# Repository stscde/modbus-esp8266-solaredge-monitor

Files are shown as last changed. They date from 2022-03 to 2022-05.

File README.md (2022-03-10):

# SolarEdge Modbus Monitor for ESP8266

This project builds a hardware monitor to show values from a SolarEdge inverter on an OLED 0.96" display.

Here is a picture of the assembled monitor showing solar data.

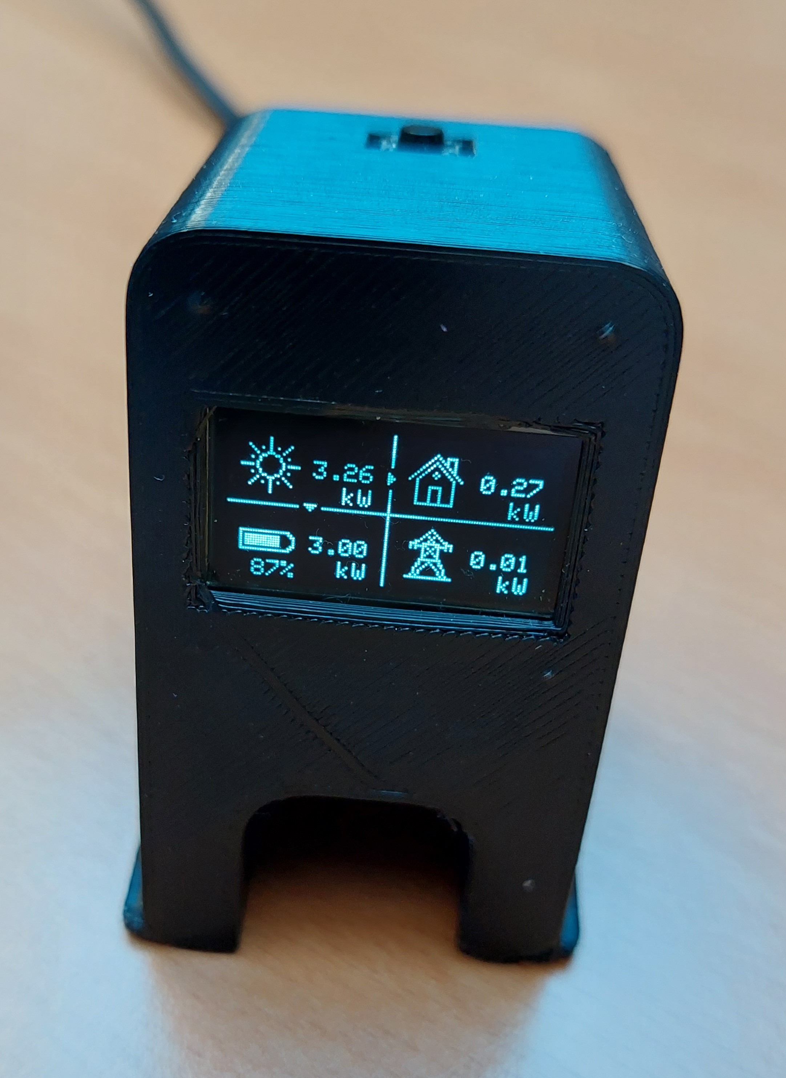
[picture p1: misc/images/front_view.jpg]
Front view


This is how the back looks like. There is a hole for connecting the monitor with USB to power or programm it.

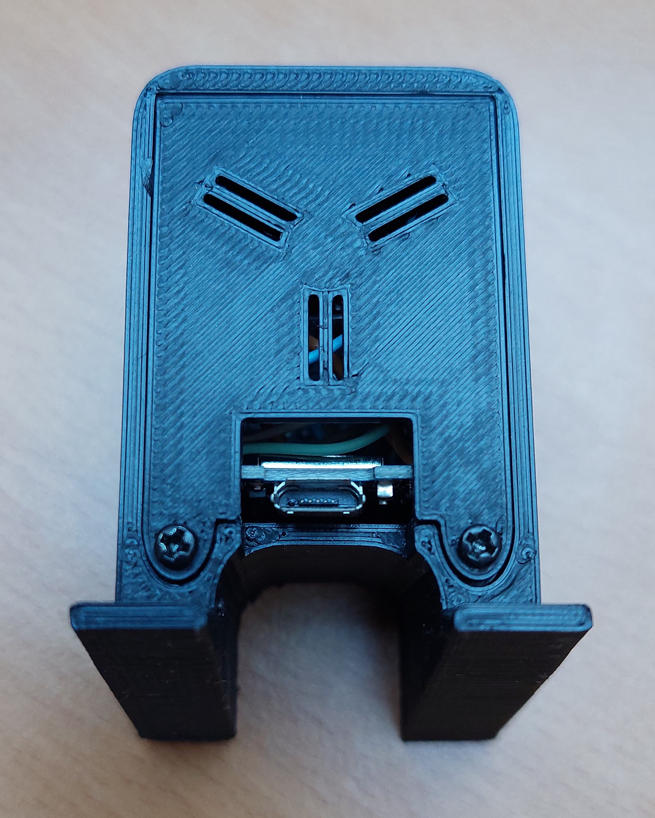
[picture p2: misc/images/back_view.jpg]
Back view


## Features

* Displays solar energy intensity
* Displays battery charge/discharge and loading state
* Displays power usage
* Displays power transfer from/to grid
* Web config interface for WIFI and Modbus connection data
* Switch button for multiple screens

## Environment

* Tested with ESP8266 on Wemos D1 mini
* Tested with SolarEdge SE7K inverter with BYD battery box
* Tested with Modbus over TCP

## Housing

I used a housing called [3D Printer Monitor for OctoPrint Wemos D1 ESP8266](https://www.thingiverse.com/thing:2884823) from [Thingiverse](https://www.thingiverse.com) build by [Qrome](https://www.thingiverse.com/qrome/designs). Many thanks for this design.

## Parts and wiring

Required parts

* Wemos D1 mini (1x)
* 0.96 incl OLED display with I2C bus (1x)
* 10k resistor (1x)
* push button (1x)

The following image shows the components and their wiring.

Electric components and wiring

## Configuration

When you start the monitor for the first time it will display "Init WiFi connection - Access Point Mode" or "Init WiFi connection - Not configured".
In both states the monitor opens an WiFi access point with SSID "SolarEdgeMonitor". Connect to this access point using your mobile or tablet. 

After the connection has been established the following config screen is shown. Fill in the values according to your environment.

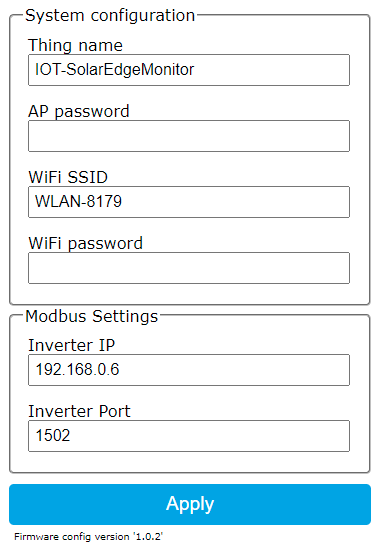
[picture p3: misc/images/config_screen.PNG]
Config screen


* Thing name: Name of the monitor in the network
* AP password: Password of the monitor´s access point. Will be required when you reconnect to the monitor after completing the configuration.
* WiFi SSID: SSID of the WiFi you want the monitor to connect to. The SolarEdge inverter has to be reachable from that WiFi.
* WiFi password: Password of the WiFi.

* Inverter IP: IP address of the SolarEdge inverter
* Inverter port: Modbus port of the SolarEge inverter

### Modbus Proxy

As my SolarEdge inverter accepts only one Modbus client I use [modbus-proxy](https://pypi.org/project/modbus-proxy/) on a Raspberry Pi. 
The proxy makes it possible for multiple clients to query data from the inverter. If you have only one client like this SolarEdge monitor connecting to the inverter you can live without a proxy of course.

### Configuration reset
You can reset the configuration by pressing the button for about 5 seconds. The display will show "Configuration reset - press again to reset". 
Press again to reset the configuration or remove power to prevent a config reset.

## Screens

There are two screens available at the moment which can be toggled by double clicking the button.

### Screen 1

Screen 1 is made up of four quadrants.

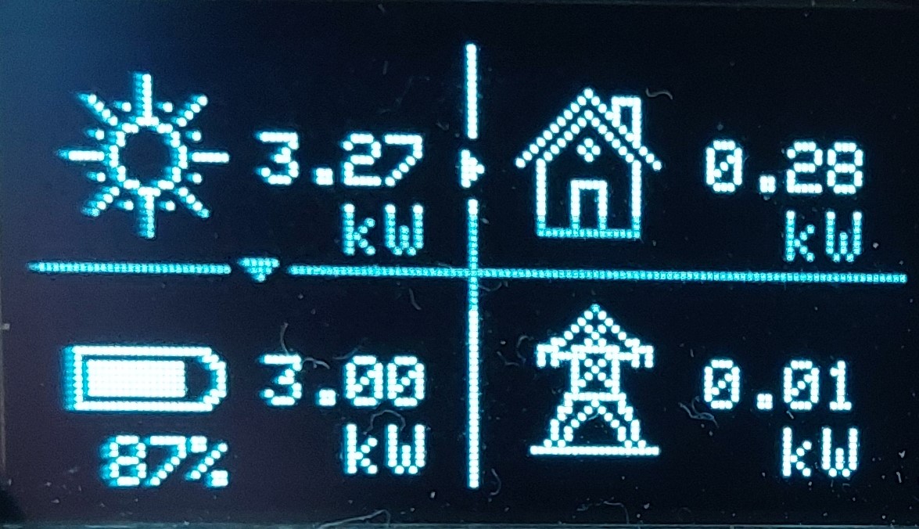
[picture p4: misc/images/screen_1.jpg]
Screen 1


* Top left - sun: shows the current power the inverter produces from the solar panels
* Bottom left - battery: shows the power transfered to (loading) and from the battery (discharging) and the fill grade of the battery.
* Top right: house: shows the power used by the house.
* Bottom right - grid: shows the power received from or sent to the power grid.

The little triangled arrows between the quadrants indicate the direction of the power flow. Example: In case the top of the triangle is pointing towards the battery then the battery is loading.

### Screen 2

Non graphical representation of the data from screen 1. Primarly used for testing screen toggling and reserved for further extensions.

## Libraries

This project uses the following libraries. Thanks to all creators and contributors.

* [emelianov/modbus-esp8266](https://github.com/emelianov/modbus-esp8266)
* [stscde/modbus-esp8266-solaredge](https://github.com/stscde/modbus-esp8266-solaredge)
* OneButton
* IotWebConf
* several Adafruit libraries

## Building

This library was created using [PlatformIO](https://platformio.org/) for [Visual Studio Code](https://code.visualstudio.com/).

To build the project with PlatformIO use the following steps:

* clone the repository from GitHub to your workspace
* compile and upload

## Last Changes

* first release no changes yet

## License

The code in this repo is licensed under the BSD New License. See LICENSE.txt for more info.

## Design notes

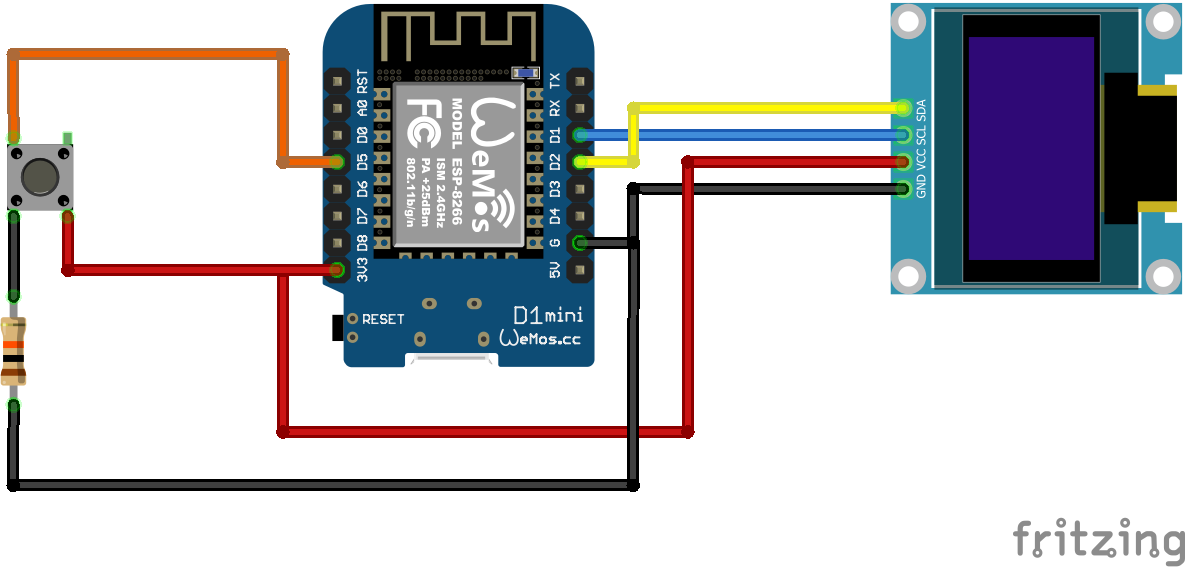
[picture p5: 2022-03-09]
misc/fritzing/solaredge_monitor.png

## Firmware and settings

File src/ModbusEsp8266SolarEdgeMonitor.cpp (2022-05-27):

#include <Adafruit_GFX.h>
#include <Adafruit_I2CDevice.h>
#include <Adafruit_SSD1306.h>
#include <Arduino.h>
#include <Fonts/FreeMono9pt7b.h>

#define IOTWEBCONF_PASSWORD_LEN 65
#include <IotWebConf.h>
#include <IotWebConfUsing.h>  // This loads aliases for easier class names.
#include <ModbusSolarEdge.h>
#include <OneButton.h>
#include <SPI.h>
#include <Wire.h>



// ### Network and modbus #####################################################
// ############################################################################


// Name server
DNSServer dnsServer;

// Web server
WebServer server(80);

// IP of the SolarEdge inverter
IPAddress remote;

// Modbus port of the SolarEdge inverter
int port = -1;

// ModbusIP object
ModbusIP mb;

// Modbus SolarEdge helper
ModbusSolarEdge mbse;


// ### IotWebConf #############################################################
// ############################################################################

// Is a reset required?
boolean needReset = false;

// Is wifi connected?
boolean connected = false;

// IotWebConf: Modifying the config version will probably cause a loss of the existig configuration. Be careful!
const char *CONFIG_VERSION = "1.0.2";

// IotWebConf: Access point SSID
const char *WIFI_AP_SSID = "SolarEdgeMonitor";

// IotWebConf: Default access point password
const char *WIFI_AP_DEFAULT_PASSWORD = "";

// IotWebConf: Method for handling access to / on web config
void handleRoot();

// IotWebConf: Called when connection to wifi was established
void wifiConnected();

// IotWebConf: Called when configuration saved
void configSaved();

// last known WiFi network state
iotwebconf::NetworkState lastNetWorkState = iotwebconf::NetworkState::OffLine;

IotWebConf iotWebConf(WIFI_AP_SSID, &dnsServer, &server, WIFI_AP_DEFAULT_PASSWORD, CONFIG_VERSION);

// Parameter group for inverter parameter
IotWebConfParameterGroup groupModbus = IotWebConfParameterGroup("groupModbus", "Modbus Settings");

// Parameter for inverter IP address
char inverterIpAddressParamValue[15] = {""};
IotWebConfTextParameter inverterIpAddressParam = IotWebConfTextParameter("Inverter IP", "inverterIpParam", inverterIpAddressParamValue, 15, "192.168.0.1");

// Parameter for Modbus TCP port
char inverterPortParamValue[32];
IotWebConfNumberParameter inverterPortParam = IotWebConfNumberParameter("Inverter Port", "inverterPort", inverterPortParamValue, 32, "1502", "1..65535", "min='1' max='65535' step='1'");


// ### Screens ################################################################
// ############################################################################

#define SCREEN_WIDTH 128  // OLED display width, in pixels
#define SCREEN_HEIGHT 64  // OLED display height, in pixels

// Declaration for an SSD1306 display connected to I2C (SDA, SCL pins)
#define OLED_RESET 0         // Reset pin # (or -1 if sharing Arduino reset pin)
#define SCREEN_ADDRESS 0x3C  ///< See datasheet for Address; 0x3D for 128x64, 0x3C for 128x32
Adafruit_SSD1306 display(SCREEN_WIDTH, SCREEN_HEIGHT, &Wire, OLED_RESET);

// which screen is currently shown
enum CurrentScreen {
    None,
    WifiState,
    Solar1,
    Solar2
};

// At boot time no screen is shown
CurrentScreen lastScreen = None;

// Time since display is on
long displayOnSince;

// Turn display off after this time in minutes to reduce OLED wearing, 0 = always on
const int DISPLAY_OFF_AFTER_MINS = 15;

// Time since last display update
long lastDisplayUpdateTime = 0;

// Update interval for display
const int DISPLAY_UPDATE_INTERVAL_SECS = 5;

// Is the display on?
boolean displayOn = true;

// Print graphical screen with solar power, battery power, house usage and grid consumption
void printStateScreen1(char *sunPowerStr, char *houseUsagePower, char *meterPower = nullptr, char *batteryPower = nullptr, char *batteryLevelOfEnergy = nullptr, float batteryLevelOfEnergyPct = 0.0f, float sunPowerPowerKw = 0.0f, float meterPowerKw = 0.0f, float houseUsagePowerKw = 0.0f, float batteryPowerKw = 0.0f, float i_ac_power_norm = 0.0f);

// Prints a simple 4 lined screen used for multiple purposes
void printStateScreen2(char *line1, char *line2, char *line3 = nullptr, char *line4 = nullptr);

// Print wifi state screen
void printWifiState();

// Main method for printing solar system usage values
void printUsage();


// ### OneButton ##############################################################
// ############################################################################

// OneButton: Handle single click
void handleClick();

// OneButton: Handle double click
void handleDoubleClick();

// OneButton: Handle long press stop
void handleLongPressStop();

OneButton btn = OneButton(
    D5,     // Input pin for the button
    false,  // Button is active LOW
    false   // Enable internal pull-up resistor
);

// Count how many times the button was pressed for a long time
int longPressCount = 0;

// ### Other method declarations ##############################################
// ############################################################################

// Helper method for rounding
float hlpRound(float f);


// ### Images #################################################################
// ############################################################################

// '211105_solaredige_mon_screen', 128x64px
const unsigned char img_background[] PROGMEM = {
    0x00, 0x00, 0x00, 0x00, 0x00, 0x00, 0x00, 0x01, 0x00, 0x00, 0x00, 0x00, 0x00, 0x00, 0x00, 0x00,
    0x00, 0x00, 0x00, 0x00, 0x00, 0x00, 0x00, 0x01, 0x00, 0x00, 0x00, 0x00, 0x00, 0x00, 0x00, 0x00,
    0x00, 0x00, 0x00, 0x00, 0x00, 0x00, 0x00, 0x01, 0x00, 0x00, 0x00, 0x00, 0x00, 0x00, 0x00, 0x00,
    0x00, 0x00, 0x00, 0x00, 0x00, 0x00, 0x00, 0x01, 0x00, 0x00, 0x00, 0x00, 0x00, 0x00, 0x00, 0x00,
    0x00, 0x00, 0x00, 0x00, 0x00, 0x00, 0x00, 0x01, 0x00, 0x00, 0x00, 0x00, 0x00, 0x00, 0x00, 0x00,
    0x00, 0x00, 0x80, 0x00, 0x00, 0x00, 0x00, 0x01, 0x00, 0x00, 0x00, 0x00, 0x00, 0x00, 0x00, 0x00,
    0x00, 0x00, 0x80, 0x00, 0x00, 0x00, 0x00, 0x01, 0x00, 0x00, 0x80, 0x00, 0x00, 0x00, 0x00, 0x00,
    0x00, 0x00, 0x80, 0x00, 0x00, 0x00, 0x00, 0x01, 0x00, 0x01, 0x4f, 0x00, 0x00, 0x00, 0x00, 0x00,
    0x00, 0x80, 0x80, 0x80, 0x00, 0x00, 0x00, 0x01, 0x00, 0x02, 0x29, 0x00, 0x00, 0x00, 0x00, 0x00,
    0x00, 0x44, 0x91, 0x00, 0x00, 0x00, 0x00, 0x01, 0x00, 0x04, 0x99, 0x00, 0x00, 0x00, 0x00, 0x00,
    0x00, 0x20, 0x82, 0x00, 0x00, 0x00, 0x00, 0x01, 0x00, 0x09, 0x49, 0x00, 0x00, 0x00, 0x00, 0x00,
    0x00, 0x11, 0xc4, 0x00, 0x00, 0x00, 0x00, 0x01, 0x00, 0x12, 0x25, 0x00, 0x00, 0x00, 0x00, 0x00,
    0x00, 0x06, 0x30, 0x00, 0x00, 0x00, 0x00, 0x01, 0x00, 0x24, 0x13, 0x00, 0x00, 0x00, 0x00, 0x00,
    0x00, 0x48, 0x09, 0x00, 0x00, 0x00, 0x00, 0x01, 0x00, 0x48, 0x89, 0x00, 0x00, 0x00, 0x00, 0x00,
    0x00, 0x08, 0x08, 0x00, 0x00, 0x00, 0x00, 0x01, 0x00, 0x91, 0x44, 0x80, 0x00, 0x00, 0x00, 0x00,
    0x00, 0x10, 0x04, 0x00, 0x00, 0x00, 0x00, 0x01, 0x01, 0x20, 0x82, 0x40, 0x00, 0x00, 0x00, 0x00,
    0x07, 0xd0, 0x05, 0xf0, 0x00, 0x00, 0x00, 0x01, 0x02, 0x40, 0x01, 0x20, 0x00, 0x00, 0x00, 0x00,
    0x00, 0x10, 0x04, 0x00, 0x00, 0x00, 0x00, 0x01, 0x00, 0x40, 0x01, 0x00, 0x00, 0x00, 0x00, 0x00,
    0x00, 0x08, 0x08, 0x00, 0x00, 0x00, 0x00, 0x01, 0x00, 0x40, 0x01, 0x00, 0x00, 0x00, 0x00, 0x00,
    0x00, 0x48, 0x09, 0x00, 0x00, 0x00, 0x00, 0x01, 0x00, 0x43, 0xe1, 0x00, 0x00, 0x00, 0x00, 0x00,
    0x00, 0x06, 0x30, 0x00, 0x00, 0x00, 0x00, 0x01, 0x00, 0x42, 0x21, 0x00, 0x00, 0x00, 0x00, 0x00,
    0x00, 0x11, 0xc4, 0x00, 0x00, 0x00, 0x00, 0x01, 0x00, 0x42, 0x21, 0x00, 0x00, 0x00, 0x00, 0x00,
    0x00, 0x20, 0x82, 0x00, 0x00, 0x00, 0x00, 0x01, 0x00, 0x42, 0x21, 0x00, 0x00, 0x00, 0x00, 0x00,
    0x00, 0x44, 0x91, 0x00, 0x00, 0x00, 0x00, 0x01, 0x00, 0x42, 0x21, 0x00, 0x00, 0x00, 0x00, 0x00,
    0x00, 0x80, 0x80, 0x80, 0x00, 0x00, 0x00, 0x01, 0x00, 0x42, 0x21, 0x00, 0x00, 0x00, 0x00, 0x00,
    0x00, 0x00, 0x80, 0x00, 0x00, 0x00, 0x00, 0x01, 0x00, 0x42, 0x21, 0x00, 0x00, 0x00, 0x00, 0x00,
    0x00, 0x00, 0x80, 0x00, 0x00, 0x00, 0x00, 0x01, 0x00, 0x7f, 0xff, 0x00, 0x00, 0x00, 0x00, 0x00,
    0x00, 0x00, 0x80, 0x00, 0x00, 0x00, 0x00, 0x01, 0x00, 0x00, 0x00, 0x00, 0x00, 0x00, 0x00, 0x00,
    0x00, 0x00, 0x00, 0x00, 0x00, 0x00, 0x00, 0x01, 0x00, 0x00, 0x00, 0x00, 0x00, 0x00, 0x00, 0x00,
    0x00, 0x00, 0x00, 0x00, 0x00, 0x00, 0x00, 0x01, 0x00, 0x00, 0x00, 0x00, 0x00, 0x00, 0x00, 0x00,
    0x00, 0x00, 0x00, 0x00, 0x00, 0x00, 0x00, 0x01, 0x00, 0x00, 0x00, 0x00, 0x00, 0x00, 0x00, 0x00,
    0x00, 0x00, 0x00, 0x00, 0x00, 0x00, 0x00, 0x01, 0x00, 0x00, 0x00, 0x00, 0x00, 0x00, 0x00, 0x00,
    0xff, 0xff, 0xff, 0xff, 0xff, 0xff, 0xff, 0xff, 0xff, 0xff, 0xff, 0xff, 0xff, 0xff, 0xff, 0xff,
    0x00, 0x00, 0x00, 0x00, 0x00, 0x00, 0x00, 0x01, 0x00, 0x00, 0x00, 0x00, 0x00, 0x00, 0x00, 0x00,
    0x00, 0x00, 0x00, 0x00, 0x00, 0x00, 0x00, 0x01, 0x00, 0x00, 0x00, 0x00, 0x00, 0x00, 0x00, 0x00,
    0x00, 0x00, 0x00, 0x00, 0x00, 0x00, 0x00, 0x01, 0x00, 0x00, 0x00, 0x00, 0x00, 0x00, 0x00, 0x00,
    0x00, 0x00, 0x00, 0x00, 0x00, 0x00, 0x00, 0x01, 0x00, 0x00, 0x00, 0x00, 0x00, 0x00, 0x00, 0x00,
    0x00, 0x00, 0x00, 0x00, 0x00, 0x00, 0x00, 0x01, 0x00, 0x00, 0x40, 0x00, 0x00, 0x00, 0x00, 0x00,
    0x00, 0x00, 0x00, 0x00, 0x00, 0x00, 0x00, 0x01, 0x00, 0x00, 0xa0, 0x00, 0x00, 0x00, 0x00, 0x00,
    0x00, 0x00, 0x00, 0x00, 0x00, 0x00, 0x00, 0x01, 0x00, 0x01, 0x10, 0x00, 0x00, 0x00, 0x00, 0x00,
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

const unsigned char img_arr_right_3x7[] PROGMEM = {
    0x00, 0x80, 0xc0, 0xe0, 0xc0, 0x80, 0x00};

// '210511_pfeil_3x7_hoch', 7x3px
const unsigned char img_arr_up_7x3[] PROGMEM = {
    0x10, 0x38, 0x7c};

// '210511_pfeil_3x7_runter', 7x3px
const unsigned char img_arr_down_7x3[] PROGMEM = {
    0x7c, 0x38, 0x10};


// ### Setup ##################################################################
// ############################################################################

void setup() {
    Serial.begin(115200);  // Start the Serial communication to send messages to the computer
    delay(10);
    Serial.println("Starting up...");

    // SSD1306_SWITCHCAPVCC = generate display voltage from 3.3V internally
    if (!display.begin(SSD1306_SWITCHCAPVCC, 0x3C)) {  // Address 0x3C for 128x64
        Serial.println(F("SSD1306 allocation failed"));
        for (;;)
            ;  // Don't proceed, loop forever
    }
    // display is built in upside down
    display.setRotation(2);
    display.clearDisplay();

    displayOnSince = millis();

    // -- Initializing the configuration.
    groupModbus.addItem(&inverterIpAddressParam);
    groupModbus.addItem(&inverterPortParam);
    iotWebConf.addParameterGroup(&groupModbus);

    iotWebConf.setWifiConnectionCallback(&wifiConnected);
    iotWebConf.setConfigSavedCallback(&configSaved);
    iotWebConf.setStatusPin(LED_BUILTIN);
    //iotWebConf.setConfigPin(D5);
    iotWebConf.init();

    // -- Set up required URL handlers on the web server.
    server.on("/", [] { iotWebConf.handleConfig(); });
    server.onNotFound([]() { iotWebConf.handleNotFound(); });

    mb.client();

    btn.attachClick(handleClick);
    btn.attachDoubleClick(handleDoubleClick);
    btn.attachLongPressStop(handleLongPressStop);

    Serial.println("setup done");
}


// ### Main ###################################################################
// ############################################################################

void loop() {
    if (needReset) {
        // config changes require reset
        Serial.println("restart in 1 sec");
        delay(1000);
        ESP.restart();
    }

    if (!connected) {
        printWifiState();
    }

    if (connected) {
        if (!mb.isConnected(remote)) {
            Serial.print("Inverter IP address: ");
            Serial.println(inverterIpAddressParamValue);
            Serial.print("Inverter TCP port: ");
            Serial.println(inverterPortParamValue);

            String line1 = "Init Modbus client";
            String ipStr(inverterIpAddressParamValue);
            String line2 = "IP: " + ipStr;
            String portStr(inverterPortParamValue);
            String line3 = "Port: " + portStr;
            String line4 = "";

            port = atoi(inverterPortParamValue);

            boolean valid = remote.fromString(inverterIpAddressParamValue);
            if (!valid) {
                line4 = "> IP is invalid";
            }
            printStateScreen2(&line1[0], &line2[0], &line3[0], &line4[0]);
            delay(2000);

            if (valid) {
                boolean connected = mb.connect(remote, port);
                line4 = connected ? "> Modbus connected" : "> Modbus conn. failed";
                printStateScreen2(&line1[0], &line2[0], &line3[0], &line4[0]);
                delay(2000);
            }
        } else {
            if ((int)millis() > lastDisplayUpdateTime + DISPLAY_UPDATE_INTERVAL_SECS * 1000 && displayOn) {
                // init to Solar1
                lastScreen = lastScreen == None || lastScreen == WifiState ? Solar1 : lastScreen;

                printUsage();

                lastDisplayUpdateTime = millis();
            }

            if (DISPLAY_OFF_AFTER_MINS != 0 && (int)millis() > displayOnSince + DISPLAY_OFF_AFTER_MINS * 60 * 1000) {
                display.ssd1306_command(SSD1306_DISPLAYOFF);
                displayOn = false;
            } else if (!displayOn) {
                display.ssd1306_command(SSD1306_DISPLAYON);
                displayOn = true;
            }
        }
    }

    iotWebConf.doLoop();
    btn.tick();
}

void handleClick() {
    Serial.println("Clicked!");
    displayOnSince = millis();  // activate Display if off
}

void handleDoubleClick() {
    Serial.println("Double Clicked!");
    displayOnSince = millis();  // activate Display if off

    if (lastScreen == Solar1) {
        lastScreen = Solar2;
    } else if (lastScreen == Solar2) {
        lastScreen = Solar1;
    }

    lastDisplayUpdateTime = 0;
}


void handleLongPressStop() {
    longPressCount++;

    String line1 = "Reset configuration";
    String line2 = "";
    String line3 = "";

    if (longPressCount == 1) {
        line2 = "Press again to reset";
        printStateScreen2(&line1[0], &line2[0], &line3[0]);
        delay(5000);
    }
    else {
        line2 = "Reset started";
        printStateScreen2(&line1[0], &line2[0], &line3[0]);
        iotWebConf.getSystemParameterGroup()->applyDefaultValue();
        iotWebConf.saveConfig();
        needReset = true;
        delay(2000);

        line2 = "Config erased";
        line3 = "Rebooting";
        printStateScreen2(&line1[0], &line2[0], &line3[0]);
        delay(5000);
    }

}

void configSaved() {
    Serial.println("config saved");
    needReset = true;
}

void wifiConnected() {
    connected = true;
    Serial.println("wifi connected");

    // hack for getting hostname set correctly
    WiFi.hostname(iotWebConf.getThingName());
    WiFi.begin();
}

void printWifiState() {
    if (iotWebConf.getState() != lastNetWorkState || lastScreen != WifiState) {
        String state = "";
        switch (iotWebConf.getState()) {
            case iotwebconf::NetworkState::ApMode:
                state = "Access Point Mode";
                break;
            case iotwebconf::NetworkState::Boot:
                state = "Booting";
                break;
            case iotwebconf::NetworkState::Connecting:
                state = "Connecting to WiFi";
                break;
            case iotwebconf::NetworkState::NotConfigured:
                state = "Not configured";
                break;
            case iotwebconf::NetworkState::OffLine:
                state = "Offline";
                break;
            case iotwebconf::NetworkState::OnLine:
                state = "Online";
                break;
        }

        String initString = "Init WiFi connection";
        printStateScreen2(&initString[0], &state[0]);

        lastNetWorkState = iotWebConf.getState();
        lastScreen = WifiState;
    }
}

void printStateScreen2(char *line1, char *line2, char *line3, char *line4) {
    display.clearDisplay();

    display.setTextSize(1);
    display.setTextColor(SSD1306_WHITE);
    display.setCursor(2, 2);
    display.println(line1);

    display.setCursor(2, 12);
    display.println(line2);

    if (line3 != nullptr) {
        display.setCursor(2, 22);
        display.println(line3);
    }

    if (line4 != nullptr) {
        display.setCursor(2, 32);
        display.println(line4);
    }

    display.display();
    delay(500);
}

void printStateScreen1(char *sunPowerStr, char *houseUsagePower, char *meterPower, char *batteryPower, char *batteryLevelOfEnergy, float batteryLevelOfEnergyPct, float sunPowerPowerKw, float meterPowerKw, float houseUsagePowerKw, float batteryPowerKw, float i_ac_power_norm) {
    display.clearDisplay();

    display.drawBitmap(0, 0, img_background, 128, 64, 1);

    display.setTextSize(1);
    display.setTextColor(SSD1306_WHITE);

    // #######
    // # Sun #
    // #######
    display.setCursor(33, 13);
    display.println(sunPowerStr);
    display.setCursor(33, 23);
    display.println("  kW");

    // #########
    // # House #
    // #########
    display.setCursor(98, 13);
    display.println(houseUsagePower);
    display.setCursor(98, 23);
    display.println("  kW");

    // print pv system to house power flow arrow
    if (i_ac_power_norm > 0) {
        display.fillRect(63, 13, 6, 9, SSD1306_BLACK);
        display.drawBitmap(62, 14, img_arr_right_3x7, 3, 7, 1);
    }

    // ###########
    // # Battery #
    // ###########

    float batteryPowerKwAbs = batteryPowerKw < 0 ? batteryPowerKw * -1 : batteryPowerKw;
    char batteryPowerFmt[4];
    dtostrf(batteryPowerKwAbs, 4, 2, batteryPowerFmt);
    String batteryPowerAbsStr(batteryPowerFmt);

    display.setCursor(33, 45);
    display.println(batteryPowerAbsStr);
    display.setCursor(33, 55);
    display.println("  kW");

    String batteryLevelOfEnergyFmt(batteryLevelOfEnergy);
    batteryLevelOfEnergyFmt += "%";

    display.setCursor(4, 57);
    display.println(batteryLevelOfEnergyFmt);

    // draw battery charge level
    const int BATT_X = 7;
    const int BATT_Y = 46;
    const int BATT_WIDTH = 17;
    const int BATT_HEIGHT = 5;

    float width = batteryLevelOfEnergyPct * BATT_WIDTH / 100.0f;
    display.fillRect(BATT_X, BATT_Y, (int)width, BATT_HEIGHT, SSD1306_WHITE);

    // print battery power flow arrow
    long batteryPowerWAbs = batteryPowerKw > 0 ? batteryPowerKw * 1000 : batteryPowerKw * -1000;
    // Serial.print("battery power w: ");
    // Serial.println(batteryPowerWAbs);
    if (batteryPowerWAbs > 9) {
        display.fillRect(28, 29, 9, 6, SSD1306_BLACK);
        if (batteryPowerKw < 0) {
            display.drawBitmap(29, 31, img_arr_up_7x3, 7, 3, 1);
        } else {
            display.drawBitmap(29, 31, img_arr_down_7x3, 7, 3, 1);
        }
    }

    // #########
    // # Meter #
    // #########

    float meterPowerKwAbs = meterPowerKw < 0 ? meterPowerKw * -1 : meterPowerKw;
    char meterPowerFmt[4];
    dtostrf(meterPowerKwAbs, 4, 2, meterPowerFmt);
    String meterPowerAbsStr(meterPowerFmt);

    display.setCursor(98, 45);
    display.println(meterPowerAbsStr);
    display.setCursor(98, 55);
    display.println("  kW");

    long meterPowerWAbs = meterPowerKwAbs * 1000;
    // print meter power flow arrow
    if (meterPowerWAbs > 9) {
        // Serial.print("meter active w: ");
        // Serial.println(meterPowerWAbs);
        display.fillRect(95, 29, 9, 6, SSD1306_BLACK);
        if (meterPowerKw < 0) {
            display.drawBitmap(96, 31, img_arr_up_7x3, 7, 3, 1);
        } else {
            display.drawBitmap(96, 31, img_arr_down_7x3, 7, 3, 1);
        }
    } else {
        Serial.print("meter inactive w: ");
        Serial.println(meterPowerWAbs);
    }

    display.display();

    // reset font to default
    display.setFont();
    delay(500);
}

void printStateScreen3(char *line1, char *line2, char *line3, char *line4) {
    display.clearDisplay();

    display.setFont(&FreeMono9pt7b);

    const int LINE_SPACE = 17;
    int y = 10;

    display.setTextSize(1);
    display.setTextColor(SSD1306_WHITE);
    display.setCursor(2, y);
    display.println(line1);

    y += LINE_SPACE;
    display.setCursor(2, y);
    display.println(line2);

    y += LINE_SPACE;
    if (line3 != nullptr) {
        display.setCursor(2, y);
        display.println(line3);
    }

    y += LINE_SPACE;
    if (line4 != nullptr) {
        display.setCursor(2, y);
        display.println(line4);
    }

    display.display();

    // reset font to default
    display.setFont();
    delay(500);
}
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

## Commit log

2022-02-03 Updated battery and meter loading indicator arrow
2022-02-03 Added settings reset on long button press Code cleanup
    [ModbusEsp8266SolarEdgeMonitor.cpp]
2022-03-09 added documentation
    [solaredge_monitor.fzz]
2022-03-09 Changed path structure for misc files
    [solaredge_monitor.fzz]
2022-05-27 renamed round to hlpRound to prevent naming conflicts
    [ModbusEsp8266SolarEdgeMonitor.cpp]
